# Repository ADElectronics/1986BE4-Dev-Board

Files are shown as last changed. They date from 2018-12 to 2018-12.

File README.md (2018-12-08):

# 1986BE4У1 Dev.Board

Отладочная плата для 1986BE4У1 в формате Arduino Mega. <br>

Firmware\ - Пример проекта прошивки для Visual Studio 2017 (Makefile проект).<br>
Hardware_v0\ - Исходная печатная плата, показанная в статье.<br>
Hardware_v1\ - Исправленная печатная плата, не заказывалась.<br>
[Статья о плате](http://adelectronics.ru/2018/12/08/делаем-arduino-mega-из-того-что-под-рукой)<br>
<br>
[WTFPL](http://www.wtfpl.net/)<br>

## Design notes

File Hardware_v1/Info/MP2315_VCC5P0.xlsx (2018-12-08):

Vout | 5.00 | R2 | 6857.142857
R1 | 36000
Vref | 0.80

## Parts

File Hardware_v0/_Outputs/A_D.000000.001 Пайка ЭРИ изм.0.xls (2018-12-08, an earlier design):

Перечень элементов
1986BE4 Dev Board
A_D.000000.001 Э3
Designator | Type | Part Number | Quantity | Specification | Manufacturer | Application Category
C1, C3, C4, C6, C24, C25, C32, C34, C35, C36, C37, C38, C39, C42, C44 | Конденсатор | GRM188R72A104KA35D | 15 |  | Murata | 1
C2 | Конденсатор | GRM188R60J106ME47D | 1 |  | Murata | 1
C5 | Конденсатор | GCJ188R72A103KA01D | 1 |  | Murata | 1
C7 | Конденсатор | GCM188R71E105KA64D | 1 |  | Murata | 1
C9, C11 | Конденсатор | GCM1885C2A120JA16D | 2 |  | Murata | 1
C15, C16, C17, C18, C19, C20, C21, C22 | Конденсатор | GCM1885C2A101JA16D | 8 |  | Murata | 1
C26, C40, C43, C45, C46, C47, C48 | Конденсатор | GRM21BR60J226ME39L | 7 |  | Murata | 1
C27, C28 | Конденсатор | GCM1885C1H150JA16D | 2 |  | Murata | 1
C29, C30, C31 | Конденсатор | GRM31CR71A226KE15L | 3 |  | Murata | 1
C33 | Конденсатор | GRM1885C2A102JA01D | 1 |  | Murata | 1
C41 | Конденсатор | GRM1885C1H330JA01D | 1 |  | Murata | 1
DA2 | Микросхема | MP2315GJ-Z | 1 |  | Monolithic Power Systems | 1
DA3 | Микросхема | LM1117MPX-3.3 | 1 |  |  | 1
DD1 | Микросхема | К1986ВЕ4У1К | 1 | АЕЯР.431280.912 ТУ | Миландр | 1
DD2 | Микросхема | STM32F103C8T6 | 1 |  | STMicroelectronics | 1
FV1 | Супрессор | USBLC6-2SC6 | 1 |  | STMicroelectronics | 1
HL1 | Индикатор единичный | BL-LS0603DNB | 1 |  |  | 1
HL2 | Индикатор единичный | BL-LS0603GC | 1 |  |  | 1
HL3 | Индикатор единичный | BL-LS0603HC | 1 |  |  | 1
L1 | Дроссель | BLM21PG331SN1 | 1 |  | Murata | 1
L2, L4 | Дроссель | BLM18PG331SN1 | 2 |  | Murata | 1
L5 | Дроссель | SRP5030T-4R7M | 1 |  | Bourns | 1
R1, R5, R27, R28, R29, R30, R32, R37, R38, R45 | Резистор | RC0603JR-0710KL | 10 |  | Yageo | 1
R2, R6, R7, R9, R55 | Резистор | RC0603JR-070R | 5 |  | Yageo | 1
R3, R36, R42 | Резистор | RC0603JR-07100R | 3 |  | Yageo | 1
R4, R46, R47 | Резистор | RC0603JR-07330RL | 3 |  | Yageo | 1
R11, R12, R13, R14, R15, R16, R17, R18, R19, R20, R21, R22, R23, R24, R25, R26 | Резистор | RC0603FR-0749R9L | 16 |  | Yageo | 1
R31 | Резистор | RC0603JR-071K5L | 1 |  | Yageo | 1
R33, R34, R51, R52, R53 | Резистор | RC0603JR-0722RL | 5 |  | Yageo | 1
R35, R43, R44 | Резистор | RC0603JR-074K7L | 3 |  | Yageo | 1
R40 | Резистор | RC0603FR-0763K4L | 1 |  | Yageo | 1
R41 | Резистор | RC0603JR-07100KL | 1 |  | Yageo | 1
R48 | Резистор | RC0603JR-0720RL | 1 |  | Yageo | 1
R49 | Резистор | RC0603JR-0733KL | 1 |  | Yageo | 1
R50 | Резистор | RC0603JR-076K8L | 1 |  | Yageo | 1
R54 | Резистор | RC0603JR-0736KL | 1 |  | Yageo | 1
SB1, SB2 | Переключатель | IT-1185AP | 2 |  |  | 1
VD1 | Диод | 1N4148WS-7-F | 1 |  | Diodes Incorporated | 1
VD2 | Стабилитрон | BZX384-C12 | 1 |  | NXP | 1
VT1 | Транзистор | IRLML9301TRPBF | 1 |  | International Rectifier | 1
VT2, VT3 | Транзистор | BC847 | 2 |  |  | 1
VT4 | Сборка транзисторная | PMC85XP | 1 |  | NXP Semiconductors | 1
XP2, XP3, XP4, XP6, XP7 | Вилка | PLS-8 | 5 |  |  | 1
XP5 | Вилка | PLS-10 | 1 |  |  | 1
XP9 | Вилка | DJK-02A | 1 |  | JIA YI | 1
XS1 | Розетка | PBD-20 | 1 |  |  | 1
XS2 | Розетка | 1981568-1 | 1 |  | TE Connectivity | 1
ZQ1 | Резонатор | AB-16.000MAGE-T | 1 |  |  | 1
ZQ3 | Резонатор | KX-9A 8.0 MHz 30/50/100 16 pF | 1 |  | Geyer | 1

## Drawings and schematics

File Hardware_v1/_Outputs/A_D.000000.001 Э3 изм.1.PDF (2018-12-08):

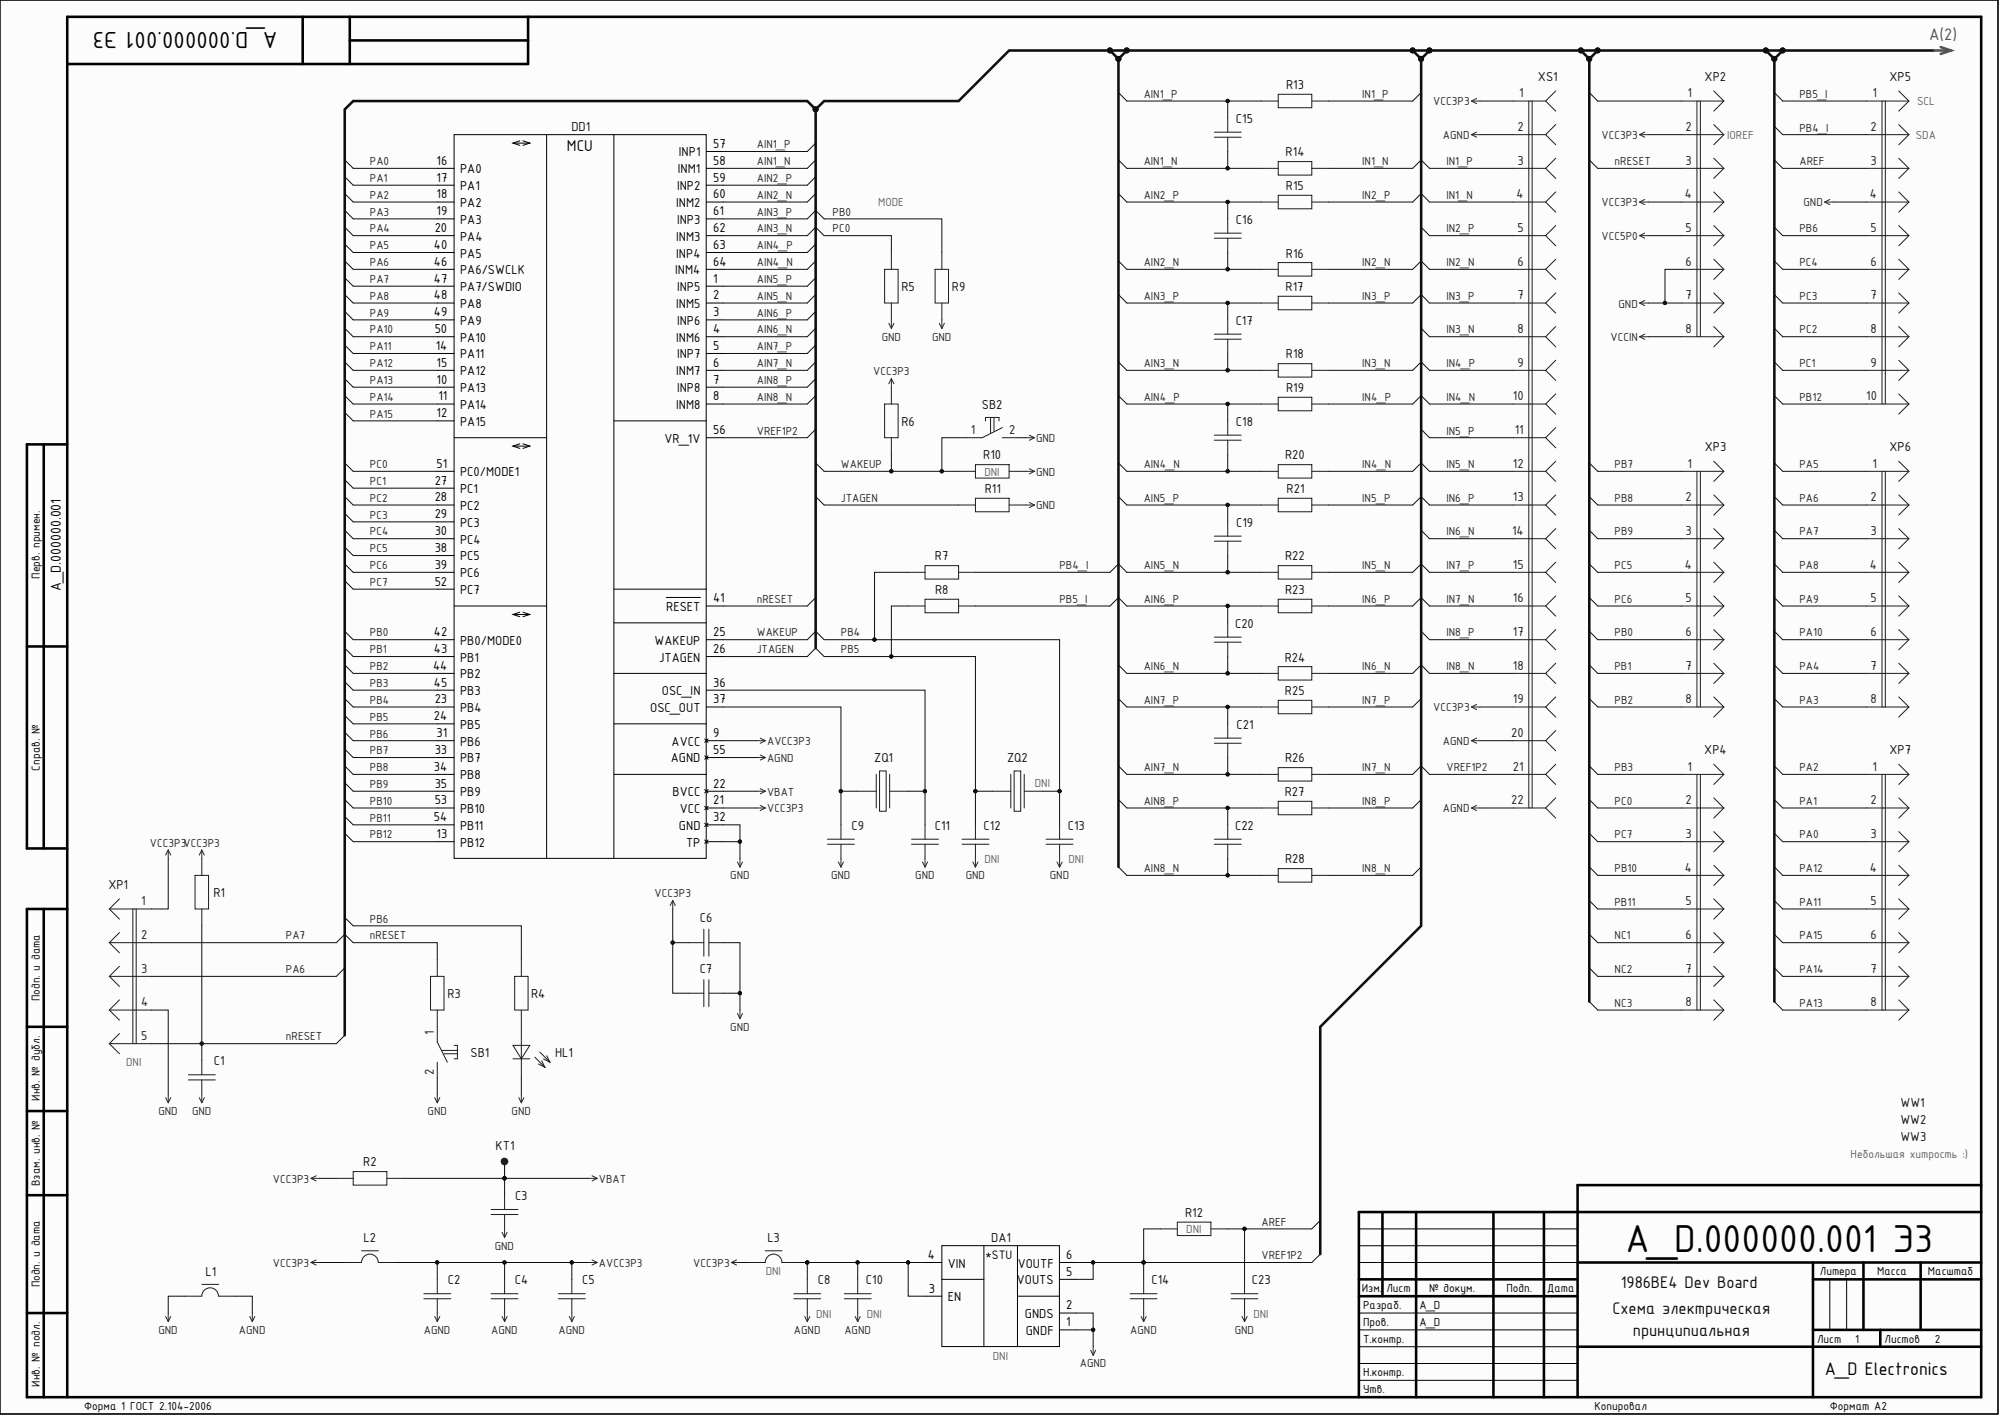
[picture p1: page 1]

Инв. № подл. Подп. и дата Взам. инв. № Инв. № дубл. Подп. и дата

VIN 4 | *STU

1986BE4 Dev Board Схема электрическая принципиальная | Литера | Масса | Масштаб

Разраб. | A_D
Пров. | A_D

Н.контр.
Утв.

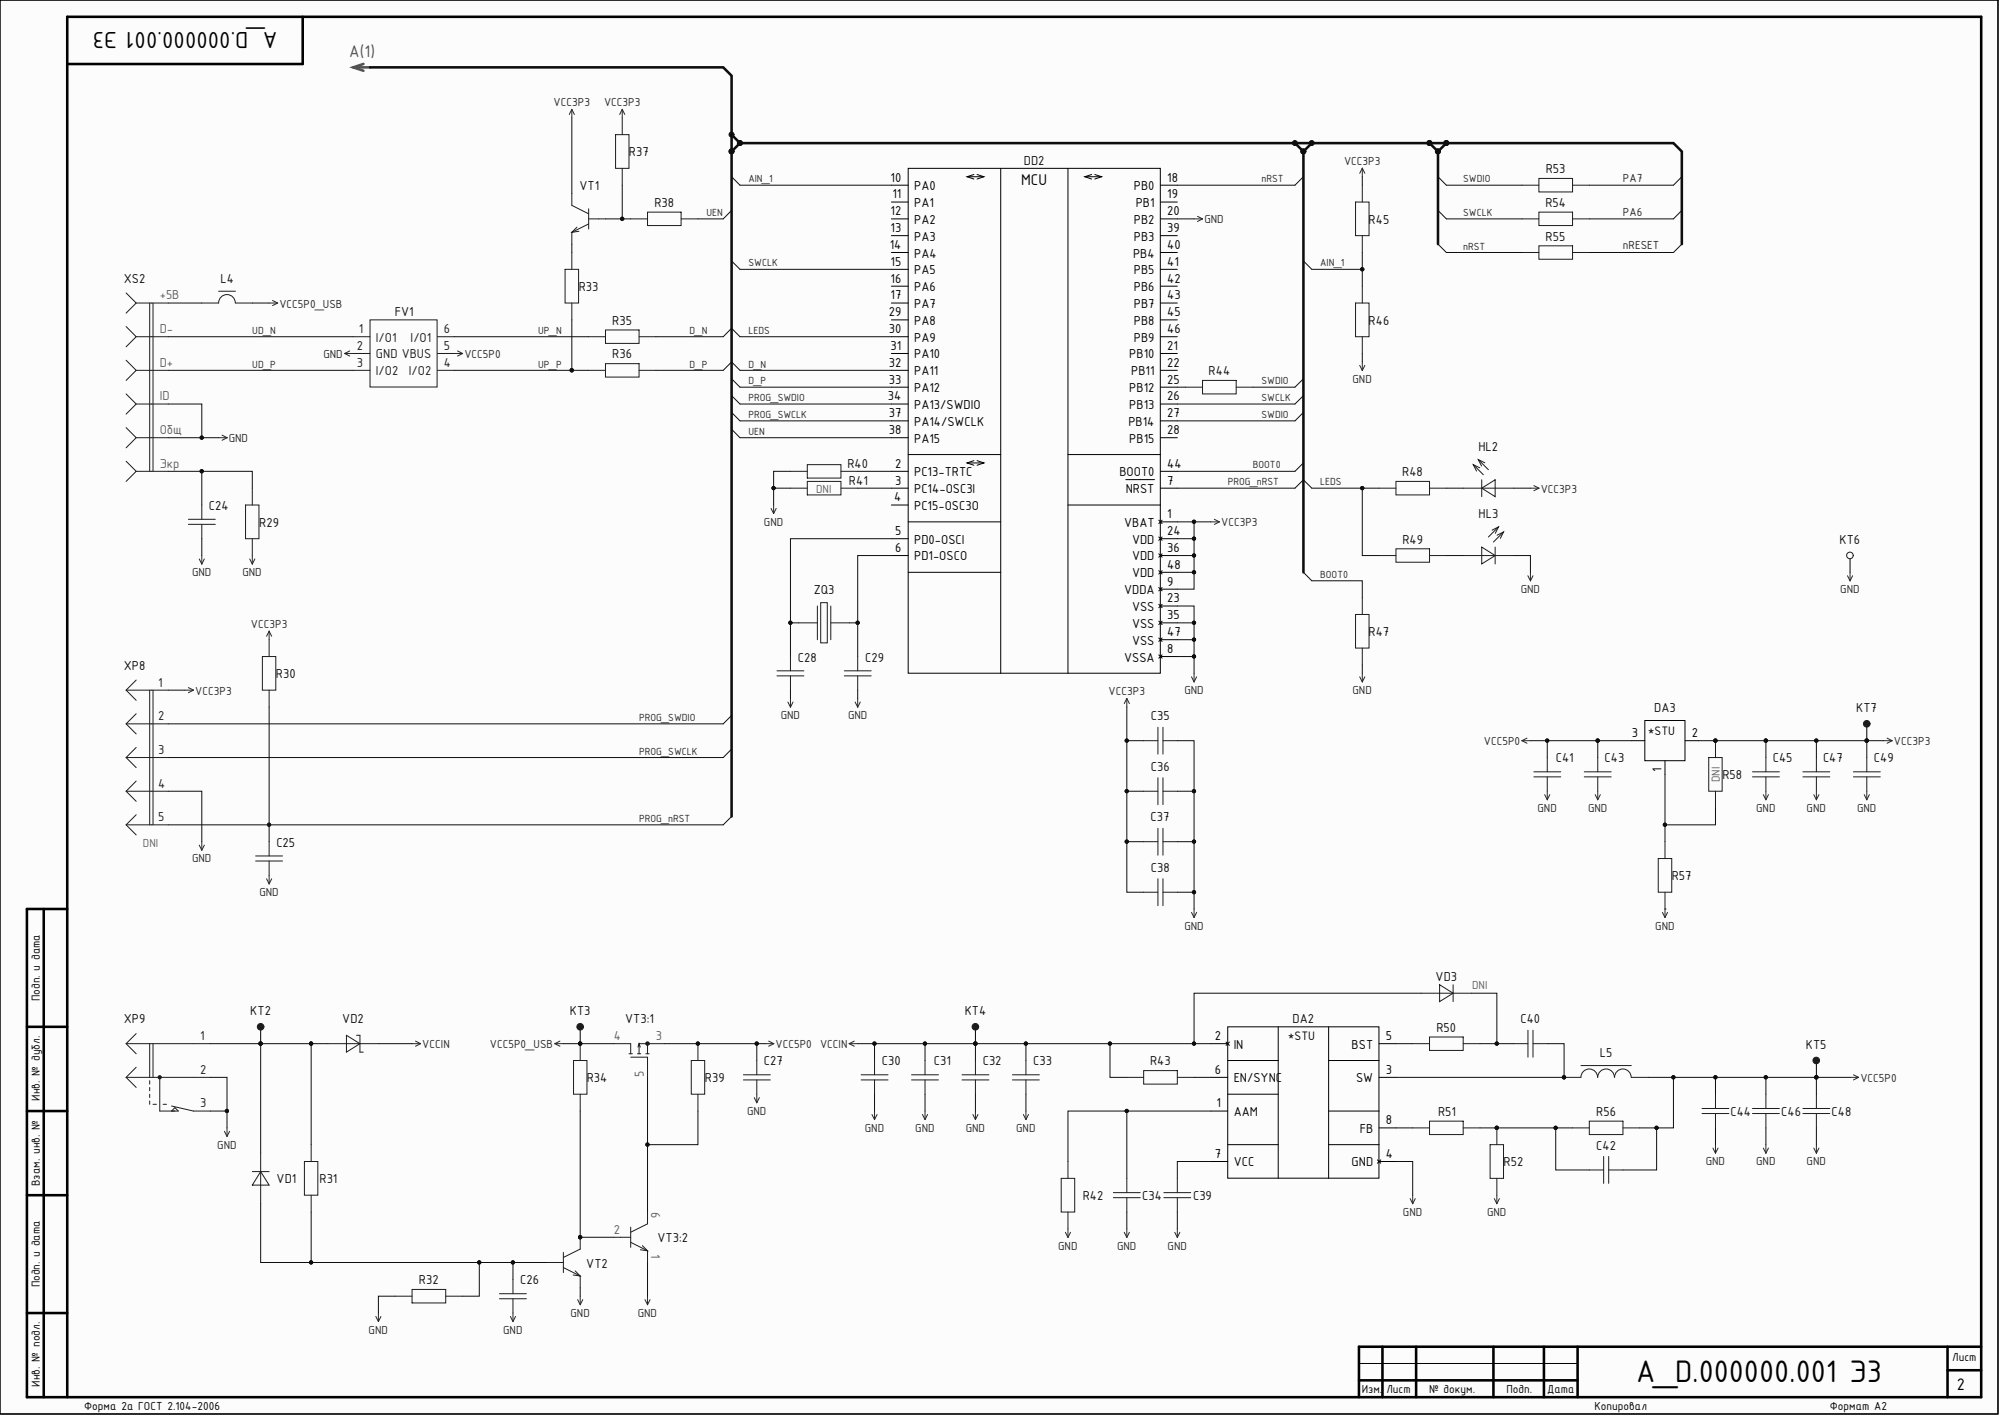
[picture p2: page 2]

Инв. № подл. Подп. и дата Взам. инв. № Инв. № дубл. Подп. и дата

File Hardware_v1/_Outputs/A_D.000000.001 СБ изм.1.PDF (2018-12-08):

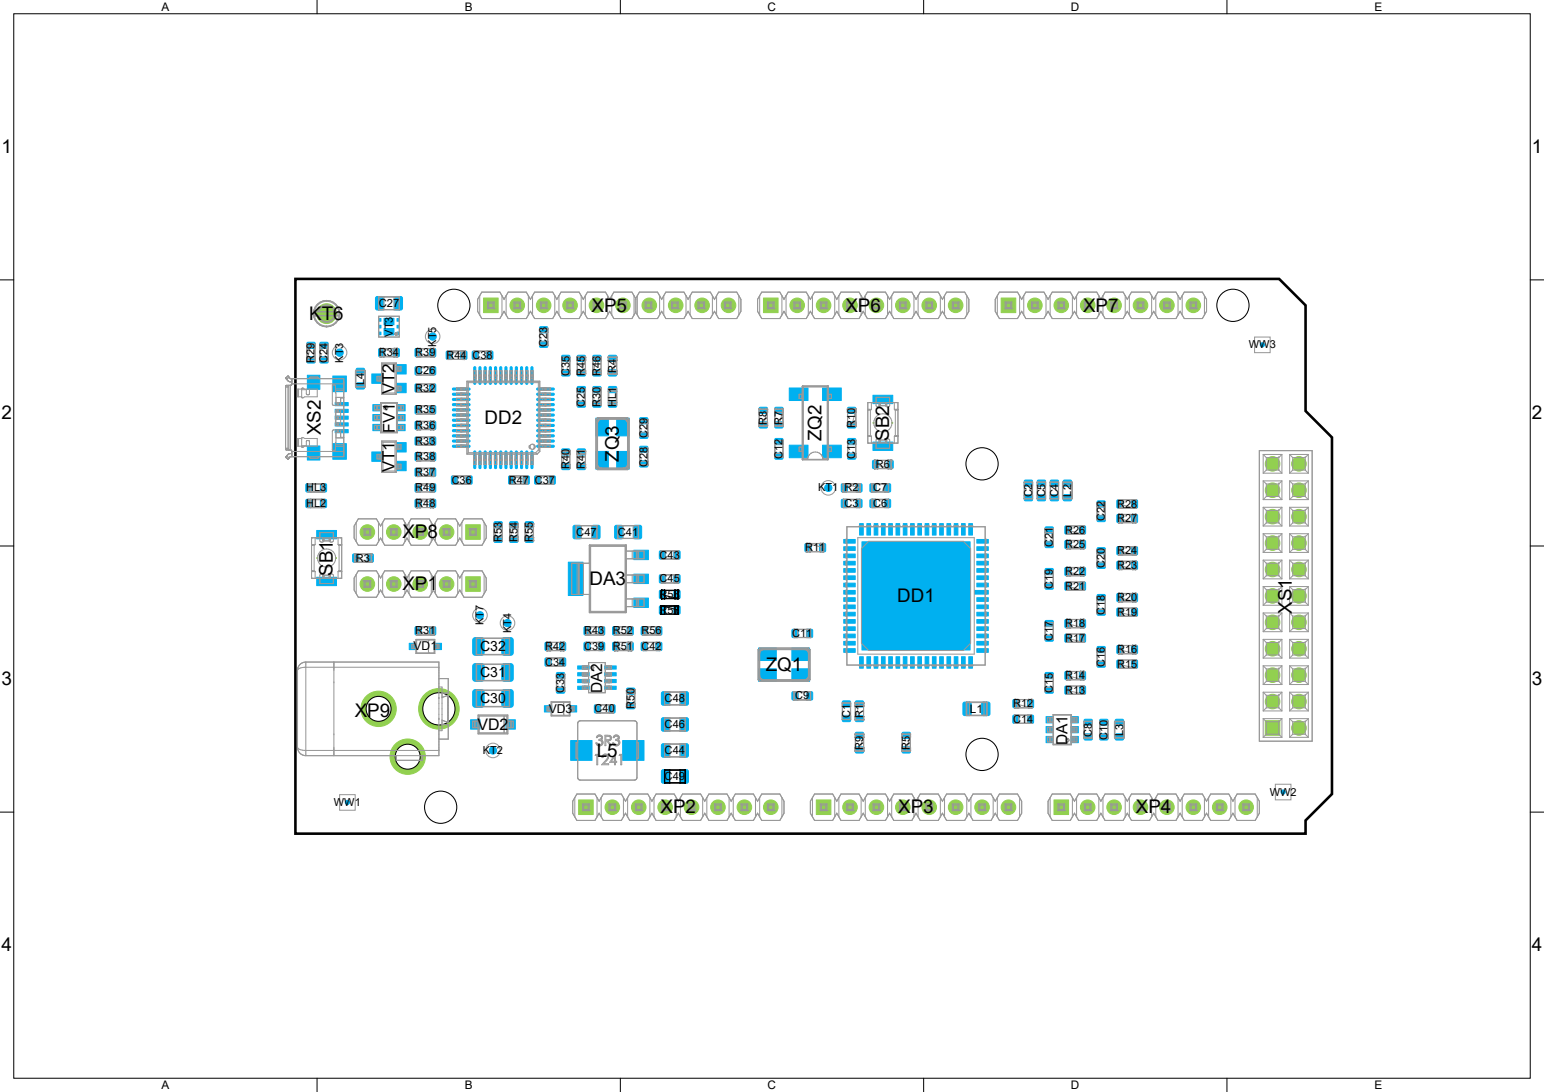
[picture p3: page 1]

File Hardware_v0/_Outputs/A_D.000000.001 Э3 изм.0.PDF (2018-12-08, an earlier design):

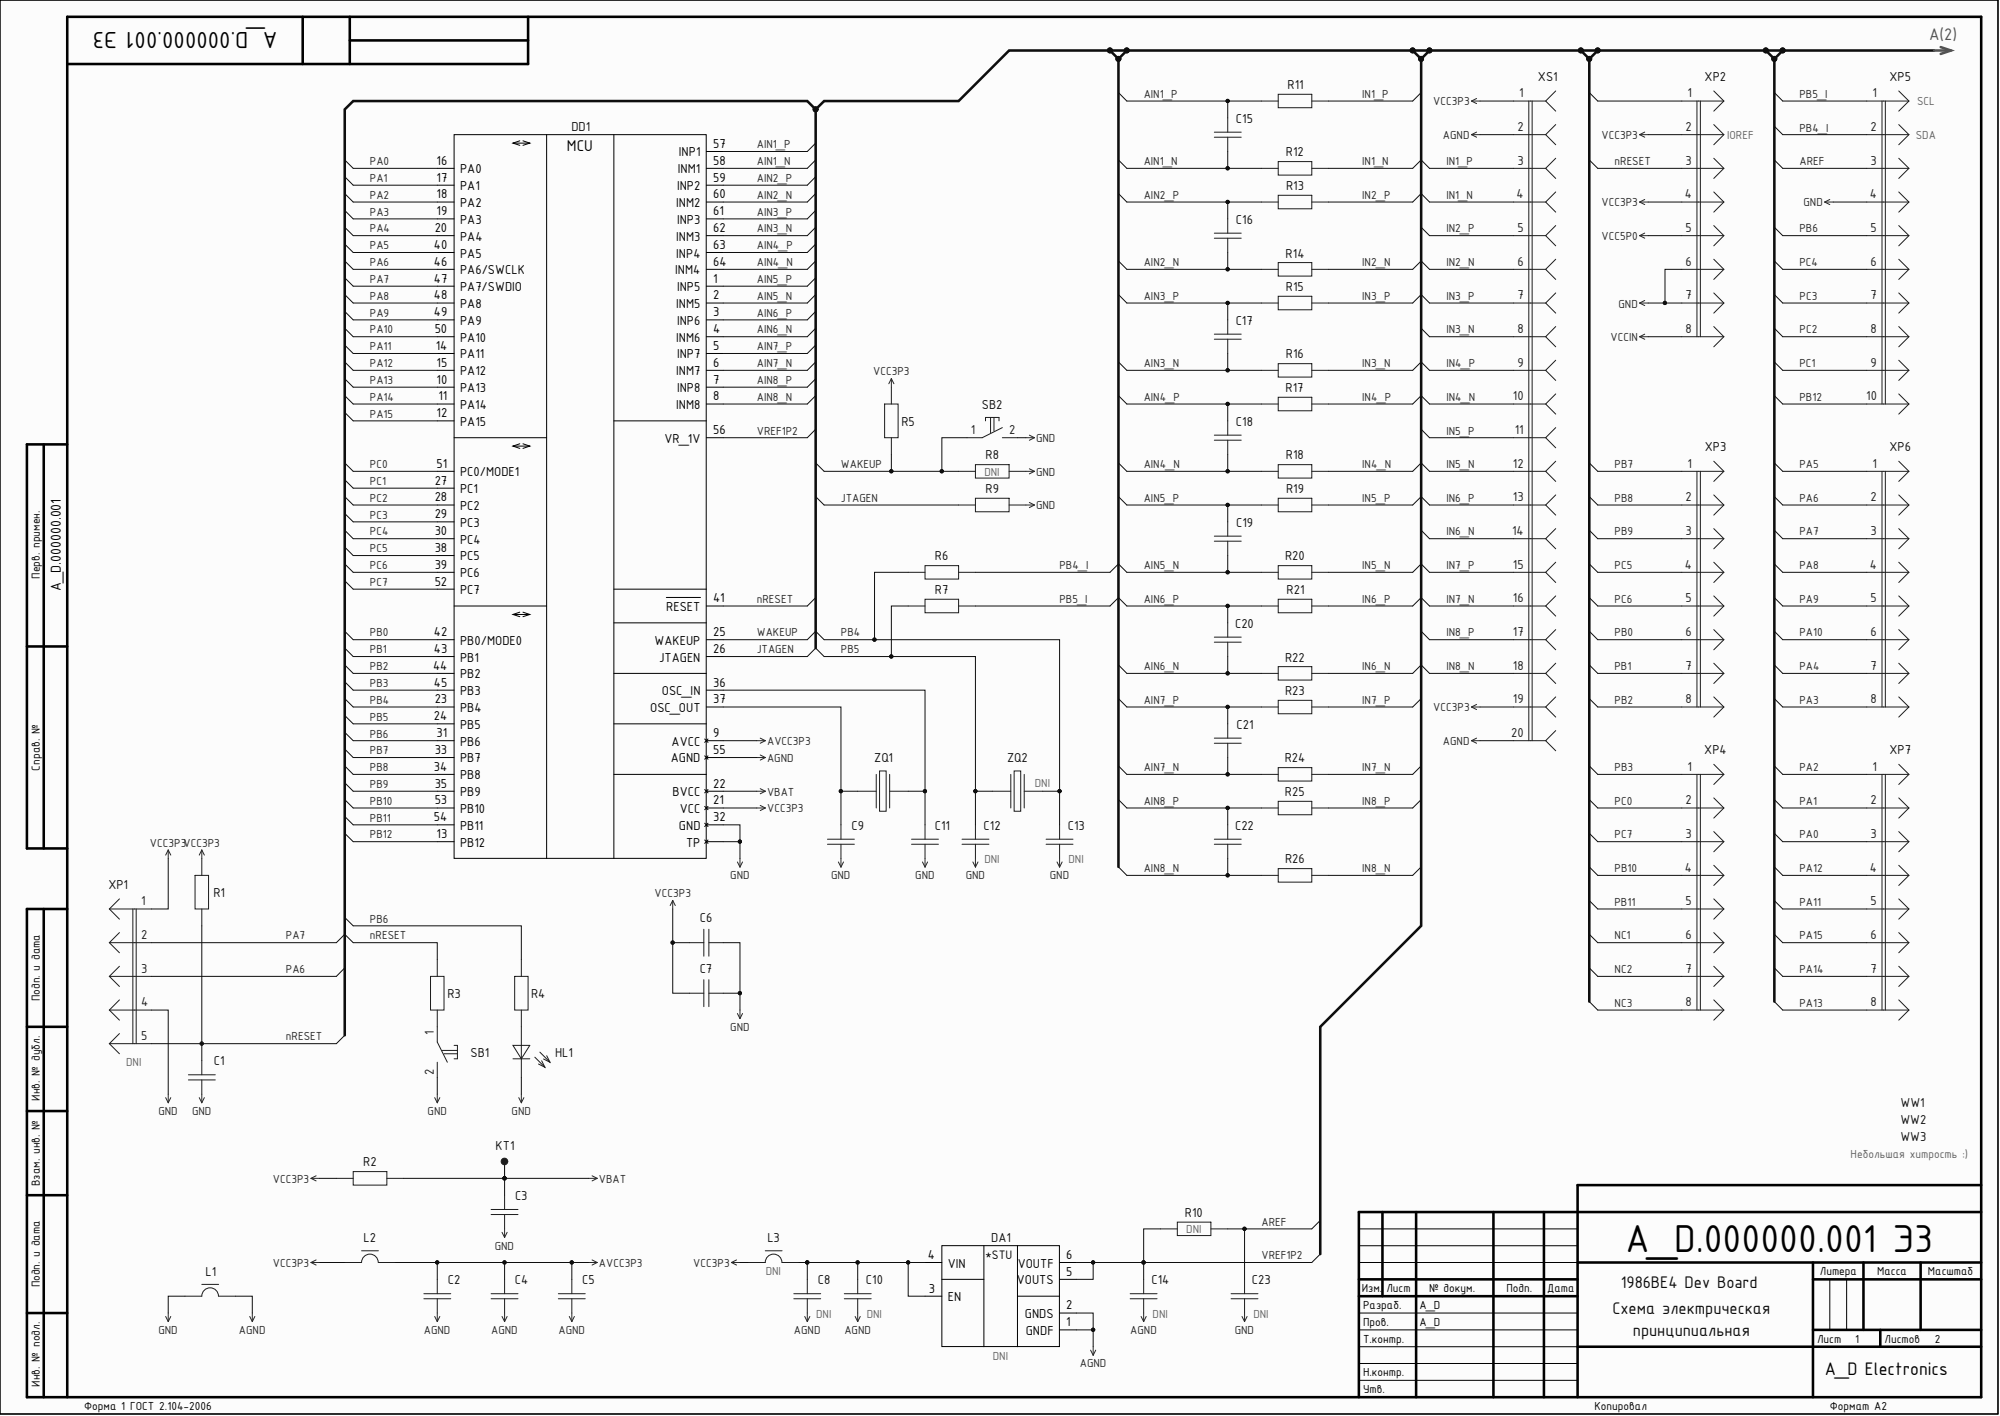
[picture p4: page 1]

Инв. № подл. Подп. и дата Взам. инв. № Инв. № дубл. Подп. и дата

VIN 4 | *STU

1986BE4 Dev Board Схема электрическая принципиальная | Литера | Масса | Масштаб

Разраб. | A_D
Пров. | A_D

Н.контр.
Утв.

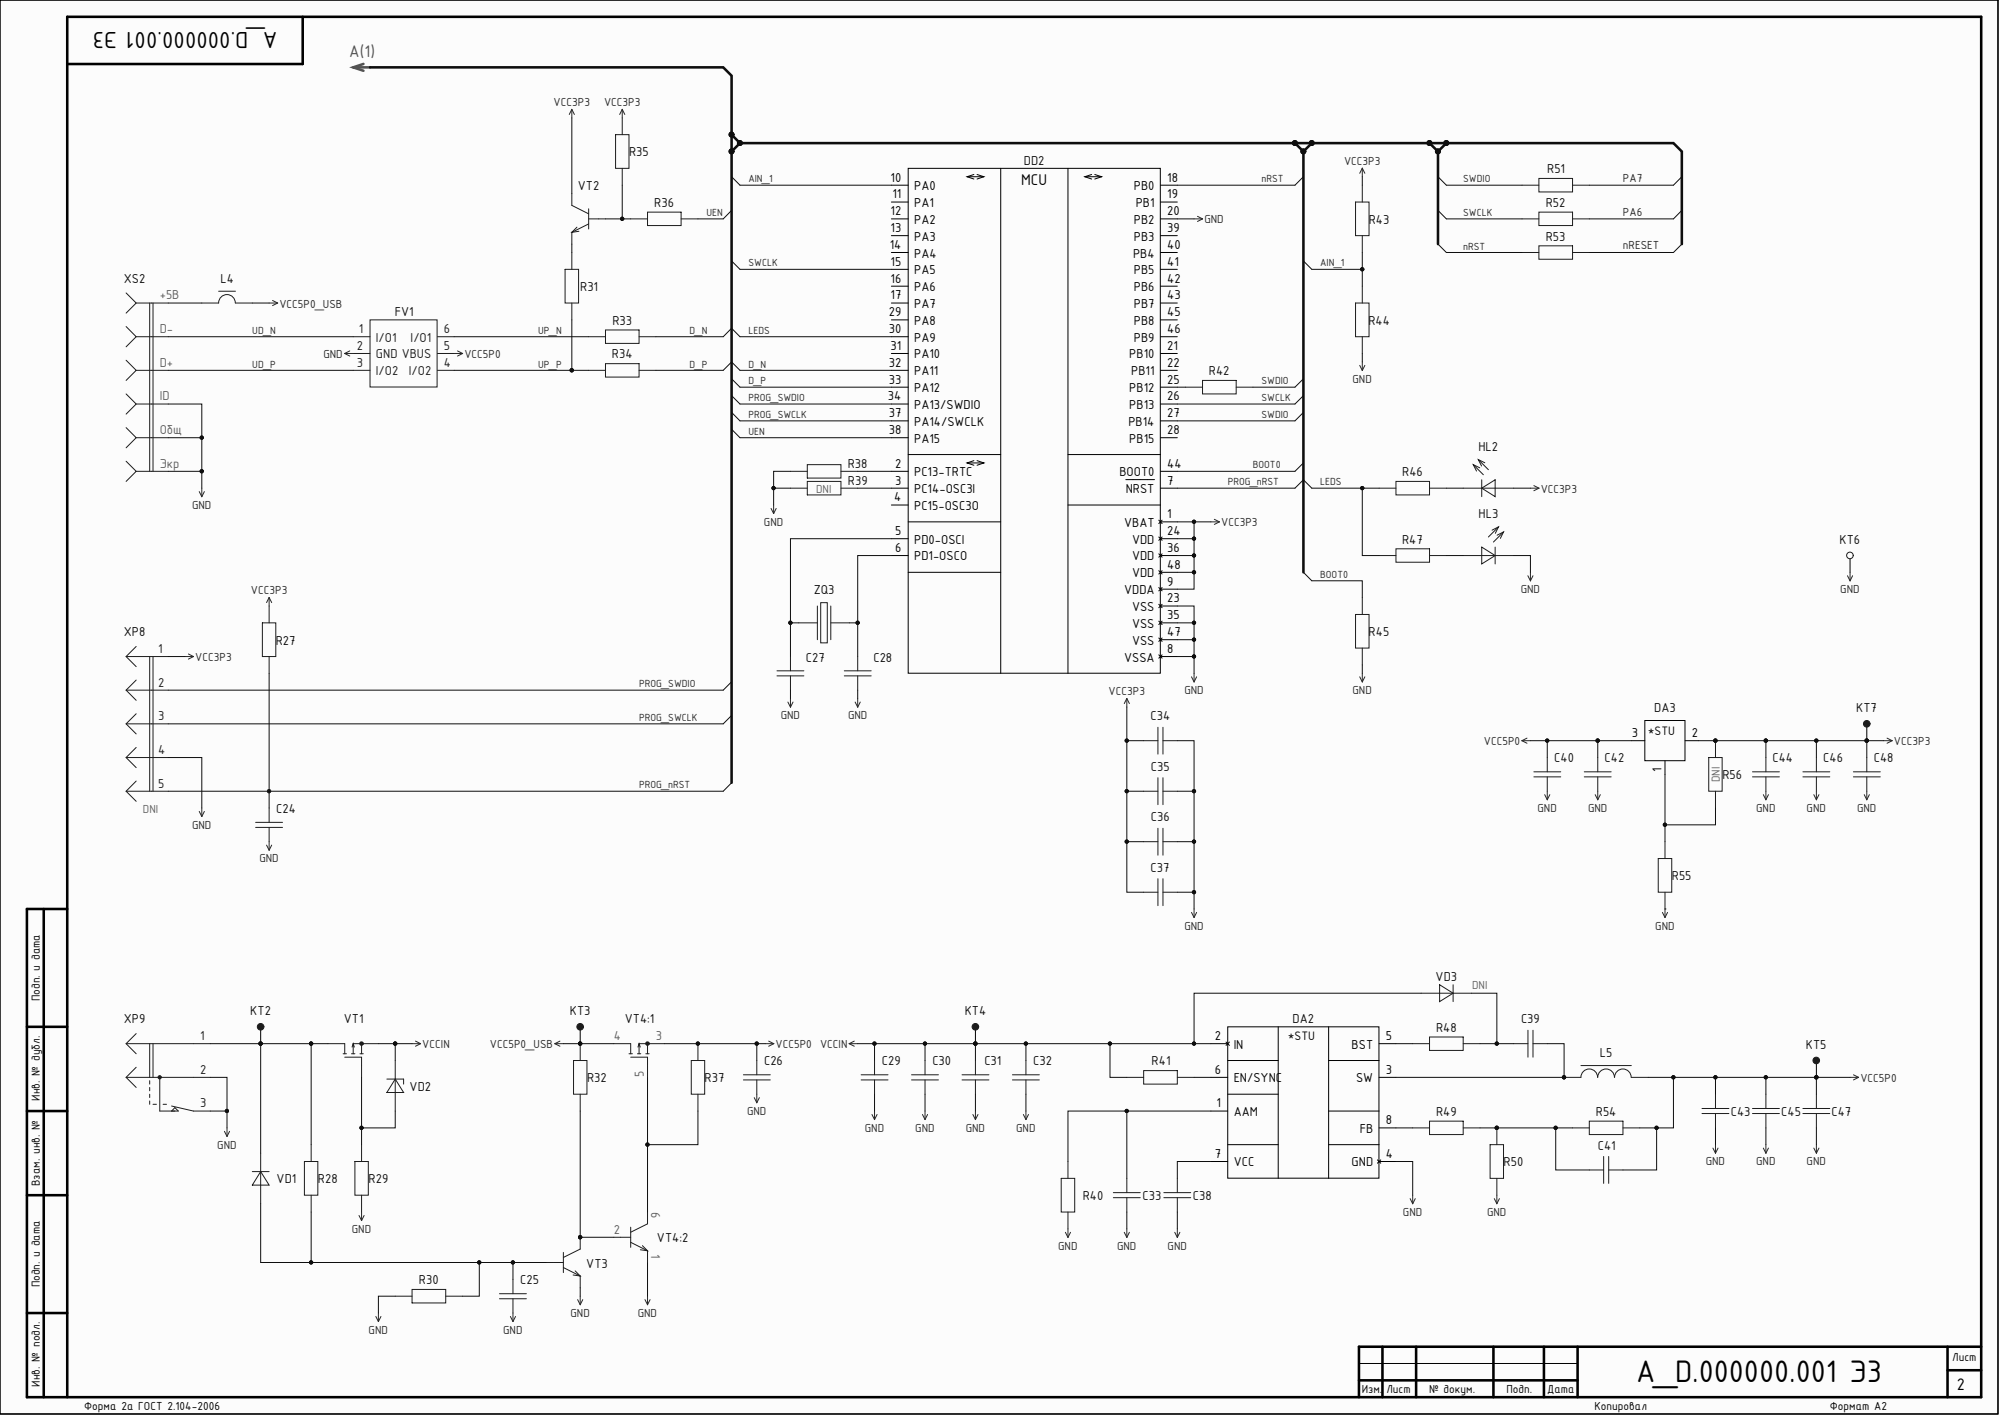
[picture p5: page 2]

Инв. № подл. Подп. и дата Взам. инв. № Инв. № дубл. Подп. и дата

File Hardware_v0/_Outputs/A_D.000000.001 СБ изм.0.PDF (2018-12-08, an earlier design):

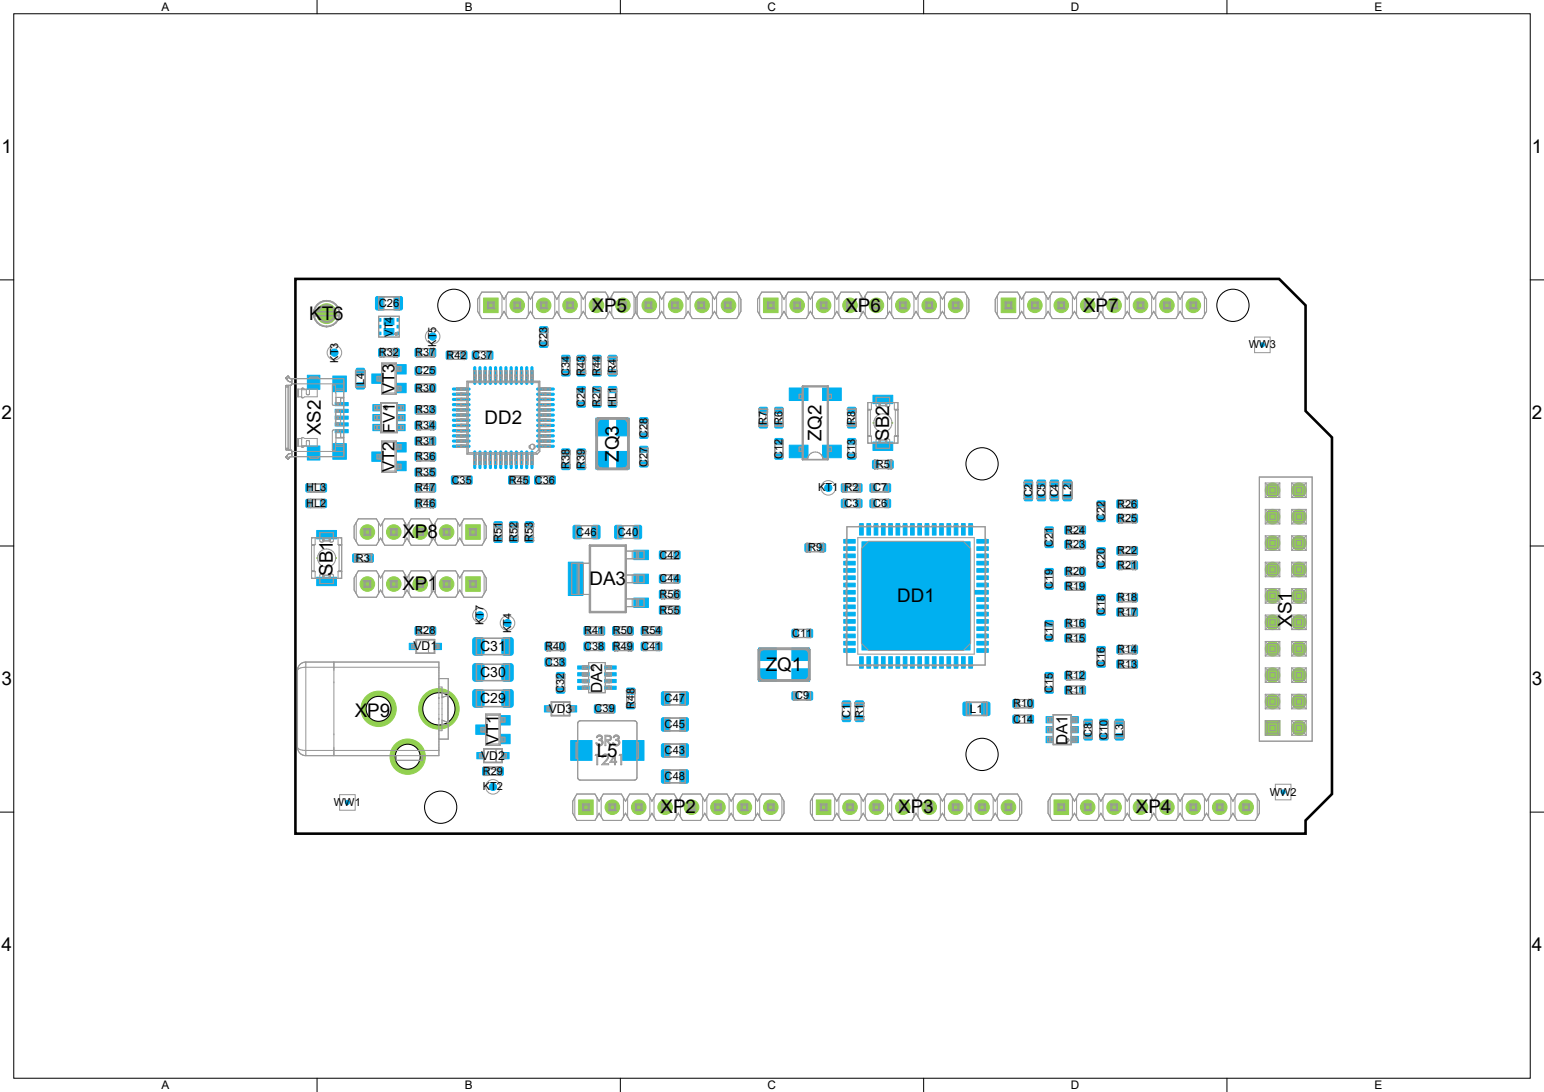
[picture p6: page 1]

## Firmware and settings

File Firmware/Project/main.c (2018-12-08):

#include "main.h"
#include "image.h"
#include <stdio.h>
#include "lcd_st7789.h"
#include "lcd_fonts.h"

#define ADCIUBUFSIZE 240
static int32_t ADCIU_Ch1[ADCIUBUFSIZE];
static uint16_t ADCIU_Counter;
static int8_t ADCIU_BufferReady = 0;

void ADCIU_PlotBuf();

// Для вывода символов printf
int __io_putchar(int ch)
{
	unsigned char c = (uint8_t)ch;
	while (UART_GetFlagStatus(MDR_UART1, UART_FLAG_TXFE) != SET);
	UART_SendData(MDR_UART1, c);
	return 0;
}

int main(void)
{
	PORT_InitTypeDef PORT_InitStructure;
	ADCIU_InitTypeDef ADCIU_InitStruct;
	ADCIU_ChannelInitTypeDef ADCIU_ChannelInitStruct;
	SSP_InitTypeDef sSSP;
	UART_InitTypeDef UART_InitStructure;
	// для вывода на экран
	char buffer[30];

	// Включаем тактирование HSE
	RST_CLK_DeInit();
	RST_CLK_CPU_PLLcmd(DISABLE);
	RST_CLK_HSEconfig(RST_CLK_HSE_ON);
	while (RST_CLK_HSEstatus() != SUCCESS) ;

	// Переключаем тактирование MCU от PLL ((8 / 2) * 8 = 32 МГц)
	//RST_CLK_CPU_PLLconfig(RST_CLK_CPU_PLLsrcHSEdiv2, RST_CLK_CPU_PLLmul8); 
	// Можно разогнать до 80 МГц !!!, но возможны проблемы с АЦП и т.д.
	RST_CLK_CPU_PLLconfig(RST_CLK_CPU_PLLsrcHSEdiv1, RST_CLK_CPU_PLLmul10); 
	RST_CLK_CPU_PLLcmd(ENABLE);
	while (RST_CLK_CPU_PLLstatus() != SUCCESS) ;

	RST_CLK_CPUclkPrescaler(RST_CLK_CPUclkDIV1);
	RST_CLK_CPU_PLLuse(ENABLE);
	// Всё тактируем от PLL
	RST_CLK_CPUclkSelection(RST_CLK_CPUclkCPU_C3 /*0x104*/);
	//RST_CLK_PCLKPer1_C1_CLKSelection(RST_CLK_PER1_C1_CLK_SRC_LSI);
	RST_CLK_PCLKPer1_C2_CLKSelection(RST_CLK_PER1_C2_CLK_SRC_PLLCPU);
	SystemCoreClockUpdate();

	// Включаем тактирование на всех портах
	RST_CLK_PCLKcmd((RST_CLK_PCLK_PORTA | RST_CLK_PCLK_PORTB | RST_CLK_PCLK_PORTC), ENABLE);

	// Тактирование периферии
	RST_CLK_PCLKcmd(RST_CLK_PCLK_SSP1, ENABLE);
	RST_CLK_PCLKcmd(RST_CLK_PCLK_UART1, ENABLE);
	RST_CLK_PCLKcmd(RST_CLK_PCLK_ADCUI, ENABLE);

	// Инициализация NVIC
	SCB->AIRCR = 0x05FA0000 | ((uint32_t)0x500);
	// Выключение всех прерываний
	NVIC->ICPR[0] = 0xFFFFFFFF;
	NVIC->ICER[0] = 0xFFFFFFFF;

	_delay_Init();

	PORT_DeInit(MDR_PORTB);
	PORT_DeInit(MDR_PORTA);

	PORT_InitStructure.PORT_Pin = LED_Pin;
	PORT_InitStructure.PORT_OE = PORT_OE_OUT;
	PORT_InitStructure.PORT_FUNC = PORT_FUNC_PORT;
	PORT_InitStructure.PORT_MODE = PORT_MODE_DIGITAL;
	PORT_InitStructure.PORT_SPEED = PORT_SPEED_FAST;
	PORT_Init(LED_Port, &PORT_InitStructure);

	// Led - ON
	PORT_SetBits(LED_Port, LED_Pin);

	// CS, DC, Reset
	PORT_InitStructure.PORT_SPEED = PORT_SPEED_MAXFAST;
	PORT_InitStructure.PORT_Pin = (SSD1306_DC_Pin | SSD1306_Reset_Pin | SSD1306_CS_Pin);
	PORT_Init(MDR_PORTA, &PORT_InitStructure);

	// PB0 - UART1_TX
	PORT_InitStructure.PORT_FUNC = PORT_FUNC_MAIN;
	PORT_InitStructure.PORT_OE = PORT_OE_OUT;
	PORT_InitStructure.PORT_Pin = PORT_Pin_0;
	PORT_Init(MDR_PORTB, &PORT_InitStructure);

	// PB1 - UART1_RX
	PORT_InitStructure.PORT_OE = PORT_OE_IN;
	PORT_InitStructure.PORT_Pin = PORT_Pin_1;
	PORT_Init(MDR_PORTB, &PORT_InitStructure);

	// SPI - SCK, MOSI
	PORT_InitStructure.PORT_OE = PORT_OE_OUT;
	PORT_InitStructure.PORT_FUNC = PORT_FUNC_MAIN;
	PORT_InitStructure.PORT_Pin = (PORT_Pin_13 | PORT_Pin_15);
	PORT_Init(MDR_PORTA, &PORT_InitStructure);

	// SPI - MISO
	PORT_InitStructure.PORT_Pin = (PORT_Pin_14);
	PORT_InitStructure.PORT_OE = PORT_OE_IN;
	PORT_Init(MDR_PORTA, &PORT_InitStructure);
	
	UART_DeInit(MDR_UART1);
	UART_BRGInit(MDR_UART1, UART_HCLKdiv1);

	UART_InitStructure.UART_BaudRate = 256000;
	UART_InitStructure.UART_WordLength = UART_WordLength8b;
	UART_InitStructure.UART_StopBits = UART_StopBits1;
	UART_InitStructure.UART_Parity = UART_Parity_No;
	UART_InitStructure.UART_FIFOMode = UART_FIFO_OFF;
	UART_InitStructure.UART_HardwareFlowControl = UART_HardwareFlowControl_RXE | UART_HardwareFlowControl_TXE; //UART_HardwareFlowControl_None;

	UART_Init(MDR_UART1, &UART_InitStructure);
	UART_Cmd(MDR_UART1, ENABLE);

	SSP_DeInit(MDR_SSP1);
	SSP_BRGInit(MDR_SSP1, SSP_HCLKdiv1);

	SSP_StructInit(&sSSP);
	sSSP.SSP_SCR = 0;
	sSSP.SSP_CPSDVSR = 2;
	sSSP.SSP_Mode = SSP_ModeMaster;
	sSSP.SSP_WordLength = SSP_WordLength8b;
	sSSP.SSP_SPH = SSP_SPH_1Edge;
	sSSP.SSP_SPO = SSP_SPO_Low;
	sSSP.SSP_FRF = SSP_FRF_SPI_Motorola;
	sSSP.SSP_HardwareFlowControl = SSP_HardwareFlowControl_None;
	SSP_Init(MDR_SSP1, &sSSP);
	SSP_Cmd(MDR_SSP1, ENABLE);

	
	printf("MCU Started...\n");
	printf("Core clock: %luHz\n", SystemCoreClock);
	
	ST7789_Init();
	ST7789_FillScreen(ST7789_BLACK);

	printf("LCD Inited...\n");
	
	
	RST_CLK_ADCIUclkDeInit();
	RST_CLK_ADCIUclkSelection(RST_CLK_ADCIUclkPLLCPU);
	RST_CLK_ADCIUclkPrescaler(RST_CLK_ADCIUclkDIV128);
	RST_CLK_ADCIUclkCMD(ENABLE);
	
	ADCIU_DeInit();
	ADCIU_StructInit(&ADCIU_InitStruct);
	ADCIU_InitStruct.ADCIU_VoltageReference = ADCIU_REFEREVCE_VOLTAGE_INTERNAL;// ADCIU_REFEREVCE_VOLTAGE_EXTERNAL;
	ADCIU_InitStruct.ADCIU_BypassBufferReference = ADCIU_BYPASS_BUFFER_REFERNCE_ENABLE;//ADCIU_BYPASS_BUFFER_REFERNCE_ENABLE;
	//ADCIU_InitStruct.ADCIU_DigitalGain = 0x00;//Gain=1
	ADCIU_Init(&ADCIU_InitStruct);

	ADCIU_ChannelStructInit(&ADCIU_ChannelInitStruct);
	ADCIU_ChannelInitStruct.ADCIU_ChopperState = DISABLE;// DISABLE;
	ADCIU_ChannelInitStruct.ADCIU_IT_FIFO_NotEmptyState = ENABLE;
	ADCIU_ChannelInitStruct.ADCIU_IT_FIFO_OverflowState = DISABLE;
	ADCIU_InitChannel(ADCIU_CHANNEL_NUMBER1, &ADCIU_ChannelInitStruct);

	NVIC_EnableIRQ(ADCIU_CH1_IRQn);
	ADCIU_ChannelCmd(ADCIU_CHANNEL_NUMBER1, ENABLE);
	printf("ADCIU Inited...\n");
	
	ST7789_DrawImage(0, 0, ST7789_WIDTH, ST7789_HEIGHT, (uint16_t *)&img);
	HAL_Delay(2000);

	//printf("ADCIU Test...\n");
	//ST7789_WriteString(0, 0, "ADCIU Test...", Font_11x18, ST7789_CYAN, ST7789_BLACK);
	//HAL_Delay(500);
	for(;;)
	{
		//PORT_SetBits(LED_Port, LED_Pin);
		//HAL_Delay(1);
		PORT_ResetBits(LED_Port, LED_Pin);

		//sprintf(buffer, "RAW: %li          ", ADCIU_Ch1[0]);
		//ST7789_WriteString(0, 0, buffer, Font_11x18, ST7789_RED, ST7789_BLACK);
		ADCIU_PlotBuf();
	}
}

void ADCIU_CH1_IRQHandler()
{
	if (ADCIU_GetStatusFlag(ADCIU_CHANNEL_NUMBER1, ADCIU_FLAG_FITO_NOT_EMPTY)) 
	{
		if (ADCIU_BufferReady == 0)
		{
			ADCIU_Ch1[ADCIU_Counter] = ADCIU_GetResult(ADCIU_CHANNEL_NUMBER1);
			if (ADCIU_Ch1[ADCIU_Counter] & (1 << 21))
				ADCIU_Ch1[ADCIU_Counter] |= (0xFF << 24);

			if (ADCIU_Counter < ADCIUBUFSIZE)
				ADCIU_Counter++;
			else
			{
				ADCIU_BufferReady = 1;
				ADCIU_Counter = 0;
			}
		}
	}
	
	if (ADCIU_GetStatusFlag(ADCIU_CHANNEL_NUMBER1, ADCIU_FLAG_FIFO_OVERFLOW))
	{
		PORT_SetBits(LED_Port, LED_Pin);
	}
}

#define ADCIU_VSCALE_MIN		(ADCIU_MIN)
#define ADCIU_VSCALE_MAX		(ADCIU_MAX)
#define ADCIU_VSCALE_PIX_MIN	0
#define ADCIU_VSCALE_PIX_MAX	239
#define ADCIU_VSCALE_GETY(x)	(int16_t)(ADCIU_VSCALE_PIX_MIN + ( x / ((ADCIU_VSCALE_MAX - ADCIU_VSCALE_MIN) / (ADCIU_VSCALE_PIX_MAX - ADCIU_VSCALE_PIX_MIN))))

void ADCIU_PlotBuf()
{
	uint8_t x;
	// для выравнивания нуля посередине
	int16_t y_offset = 240;

	if (ADCIU_BufferReady)
	{
		for (x = 0; x < ST7789_WIDTH; x++)
		{
			int32_t y_cur = ADCIU_GETV_I32(ADCIU_Ch1[x]);

			ST7789_FillRectangle(x, 0, 1, ST7789_HEIGHT, ST7789_BLACK);
			ST7789_DrawPixel(x, y_cur + y_offset, ST7789_MAGENTA);
		}
		ADCIU_BufferReady = 0x00;
	}
}

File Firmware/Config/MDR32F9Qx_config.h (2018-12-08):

/**
  ******************************************************************************
  * @file    MDR32F9Qx_Demo\Project\Demo\MDR32F9Qx_config.h
  * @author  Milandr Application Team
  * @version V1.2.0
  * @date    10/07/2010
  * @brief   Library configuration file.
  ******************************************************************************
  * <br><br>
  * THE PRESENT FIRMWARE WHICH IS FOR GUIDANCE ONLY AIMS AT PROVIDING CUSTOMERS
  * WITH CODING INFORMATION REGARDING THEIR PRODUCTS IN ORDER FOR THEM TO SAVE
  * TIME. AS A RESULT, MILANDR SHALL NOT BE HELD LIABLE FOR ANY
  * DIRECT, INDIRECT OR CONSEQUENTIAL DAMAGES WITH RESPECT TO ANY CLAIMS ARISING
  * FROM THE CONTENT OF SUCH FIRMWARE AND/OR THE USE MADE BY CUSTOMERS OF THE
  * CODING INFORMATION CONTAINED HEREIN IN CONNECTION WITH THEIR PRODUCTS.
  *
  * <h2><center>&copy; COPYRIGHT 2014 Milandr</center></h2>
  */

/**
 * @mainpage MDR32F9Qx Standard Peripherals Library.
 * MDR32F9Qx Standard Peripherals Library is a package consisting of
 * all standard peripheral device drivers for 1986BE9x, K1986BE9x, MDR32F9Qx,
 * 1986VE1T, 1986VE3T, 1986VE7T microcontrollers.
 * This library is a firmware package which contains a collection of routines,
 * data structures and macros covering the features of Milandr MDR32F9Qx
 * peripherals. It includes a description of the device drivers plus a set of
 * examples for each peripheral. The firmware library allows any device to be
 * used in the user application without the need for in-depth study of each
 * peripherals specifications. Using the Standard Peripherals Library has two
 * advantages: it saves significant time that would otherwise be spent in
 * coding, while simultaneously reducing application development and
 * integration costs.
 *
 * The MDR32F9Qx Standard Peripherals Library is compatible with Milandr
 * 1986BE9x evaluation boards, Milandr evaluation board for MC 1986VE1T
 * (EVAL 22.0 B) and evaluation board for MC 1986VE3T.
 *
 * The MDR32F9Qx Standard Peripherals Library is full CMSIS compliant.
 */

/* Define to prevent recursive inclusion -------------------------------------*/
#ifndef __MDR32F9Qx_CONFIG_H
#define __MDR32F9Qx_CONFIG_H

#ifdef __cplusplus
extern "C" {
#endif

#if ((__CC_ARM == 0) || (__ARMCC_VERSION < 5000000))
	#include "MDR32F9Qx_board.h"
#endif
#include "MDR32F9Qx_lib.h"
#include <stdint.h>

#if defined (USE_MDR32F9Q1_Rev0) || defined (USE_MDR32F9Q1_Rev1) ||\
    defined (USE_MDR32F9Q2_Rev0) || defined (USE_MDR32F9Q2_Rev1) ||\
    defined (USE_MDR32F9Q3_Rev0) || defined (USE_MDR32F9Q3_Rev1) ||\
    defined (USE_MDR1986VE94)
	#define USE_MDR1986VE9x
#endif

#if defined (USE_MDR1986BE7T)
	#define USE_MDR1986VE1T
#endif

/* Select the header file for target microcontroller */
#if defined ( USE_MDR1986VE9x )
	#include "MDR32Fx.h"
#elif defined (USE_MDR1986VE1T)
	#include "MDR1986VE1T.h"
#elif defined ( USE_MDR1986VE3 )
	#include "MDR1986VE3.h"
#elif defined ( USE_MDR1901VC1T )
	#include "MDR1901VC1T.h"
#elif defined (USE_MDR1986BE4)
	#include "MDR1986BE4.h"
#endif

/* Uncomment the line(s) below to define used JTAG port(s). Leave all commented
 * if there is no JTAG ports */
#if (defined(USE_MDR1986VE9x) || defined (USE_MDR1901VC1T))
/* #define USE_JTAG_A */
#define USE_JTAG_B
#endif

/* Target system parameters */
/* RST_CLK generators frequencies in HZ */
#define HSI_Value       ((uint32_t)8000000)
#define HSE_Value       ((uint32_t)8000000)//((uint32_t)16000000)
#define HSE2_Value      ((uint32_t)25000000)
#define LSI_Value       ((uint32_t)40000)
#define LSE_Value       ((uint32_t)32768)

/* RST_CLK frequencies startup timeouts settings */
#define HSEonTimeOut    ((uint16_t)0x0600)
#define HSE2onTimeOut	((uint16_t)0x8000)
#define LSEonTimeOut    ((uint16_t)0x0600)
#define HSIonTimeOut    ((uint16_t)0x0600)
#define LSIonTimeOut    ((uint16_t)0x0600)
#define PLLCPUonTimeOut ((uint16_t)0x0600)
#define PLLUSBonTimeOut ((uint16_t)0x0600)
#define PLLDSPonTimeOut ((uint16_t)0x0600)

/* EEPROM programming the max MCU frequency */
/* #define FLASH_PROG_FREQ_MHZ     (8.0) */

/* Use debug uart */
/* #define _USE_DEBUG_UART_ */

#if defined (_USE_DEBUG_UART_)

#define DEBUG_BAUD_RATE					115200
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

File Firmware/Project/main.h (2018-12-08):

#ifndef __MAIN_H__
#define __MAIN_H__

#include "MDR32F9Qx_config.h"
#include "MDR32F9Qx_port.h"
#include "MDR32F9Qx_ssp.h"
#include "MDR32F9Qx_rst_clk.h"
#include "MDR32F9Qx_uart.h"
#include "MDR32F9Qx_adciu.h"

#include "delay.h"
#include <math.h> 

#define SSD1306_USE_SPI
#define SSD1306_SPI_PORT		
// MOSI - PA15
// MISO - PA14
// SCK - PA13
#define LED_Port				MDR_PORTB
#define LED_Pin					PORT_Pin_6

#define SSD1306_CS_Port         MDR_PORTA
#define SSD1306_CS_Pin          PORT_Pin_0
#define SSD1306_DC_Port         MDR_PORTA
#define SSD1306_DC_Pin          PORT_Pin_11
#define SSD1306_Reset_Port      MDR_PORTA
#define SSD1306_Reset_Pin       PORT_Pin_12
//#define SSD1306_INVERSE_COLOR

#define ST7789_CS_Port			MDR_PORTA
#define ST7789_CS_Pin			PORT_Pin_0
#define ST7789_DC_Port			MDR_PORTA
#define ST7789_DC_Pin			PORT_Pin_11
#define ST7789_Reset_Port		MDR_PORTA
#define ST7789_Reset_Pin		PORT_Pin_12

// Для удобства (и привычки :D)
#define HAL_Delay(ms) _delay_ms(ms)


// ADCIU
#define ADCIU_MAX				0xFFFFFF
#define ADCIU_MIN				0x0
#define ADCIU_VREF				1.20F
#define ADCIU_AGAIN				1.0F
#define ADCIU_ADCPGA			00.0F//42.0F
#define ADCIU_DGAIN				(powf(10,(ADCIU_ADCPGA/20.0F)))
//#define ADCIU_GETV(bits)		(float)((2.0F * ADCIU_VREF * ADCIU_AGAIN * ADCIU_DGAIN * powf(2,22)) / (bits - powf(2,23)))
#define ADCIU_GETV_F(bits)		(float)((2.0F * ADCIU_VREF * ADCIU_AGAIN * ADCIU_DGAIN * 4194304.0F) / (bits - 8388608.0F))
#define ADCIU_GETV_I32(bits)	(int32_t)(100.0F * ((2.0F * ADCIU_VREF * ADCIU_AGAIN * ADCIU_DGAIN * 4194304.0F) / (bits - 8388608.0F)))
#endif // __MAIN_H__

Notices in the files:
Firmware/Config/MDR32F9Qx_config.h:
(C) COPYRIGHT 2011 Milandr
